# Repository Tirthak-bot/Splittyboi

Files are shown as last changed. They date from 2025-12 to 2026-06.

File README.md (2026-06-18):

# Splittyboi
A Split keyboard with low profile switches, Coded with KMK Firmware.

Split keeb Zine Page
Untitled design (1)

Making this because i want to try a split keeb :3

Using this is pretty straight forward obviously blehh, just connect it to the computer, flash the firmware once and it should just work like a regular keeb moving forward :)

# Schematic
This is the schematic for a single side, both sides are made identically.



# Layout
The layout was designed on https://www.keyboard-layout-editor.com/, The firmware hasn't yet been edited to match this layout and is currently sitting with placeholders.



# PCB
The PCB was designed in Kicad. The matrix wasn't properly aligned to make the look of the PCB More intresting, it will be coded in properly afterwards (Once I make it IRL).




# Case
The case was designed in Fusion. Both sides of the case are based on the same footprint but once it is extruded in the positive axis and once in negetive axis to get a identical case accommodating both right and left sides.

You just drop the pcb in place :) and for the both halfs of the case, they join using magnets!

The magnets are glue and drop, not press fit! So the thin walls around the magnet holes won't cause any problems!

Split_keeb_final_assembly_2026-Jun-13_07-47-10AM-000_CustomizedView16534653009

# Firmware
As mentioned above, the firmware is written in python using the KMK Libraries. It will be pushed to the microcontroller using circuit python.

# BOM
|SR.NO|ITEMS|QUANTITY|UNIT PRICE|TOTAL PRICE|URL|
|-----|-----|---|---|---|---|
|1|PCB (From JLCPCB)|5 (Minimun)|$10 (Including Shipping)|$50|In my Cart|
|2|Seeed XIAO nRF52840|2 (One for each side)|$12.50 (Including Shipping)|$25|https://robocraze.com/products/seeed-studio-xiao-nrf52840-development-board-supports-bluetooth-5-0|
|3|Gateron LP 2.0 Switches|70|$0.185 (Including Shipping)|$13|https://meckeys.com/shop/accessories/keyboard-accessories/key-switches/gateron-low-profile-2-0-mechanical-switch-3pin/|
|4|Blank DSA Keycaps 1U|70|$0.207 (Including Shipping)|$14.5|https://meckeys.com/shop/accessories/keyboard-accessories/keycaps/blank-dsa-keycaps-1u/|
|5|3.7V LiPo Batteries|2 (One for each side)|$1.615 (Including Shipping)|$3.23|https://quartzcomponents.com/products/3-7v-1000mah-li-po-rechargeable-battery|
|6|1N4148WS T4 Switching Diode|70|$0.025 (Including Shipping)|$1.78|https://quartzcomponents.com/collections/smd-diodes/products/1n4148ws-t4-switching-diode-sod-123-smd-package|
|7|3D Prints|4 Files|idk|idk|Self printed|
|8|Magnets|14|$0|$0|Self sourced|
|Total:|||-|$110||

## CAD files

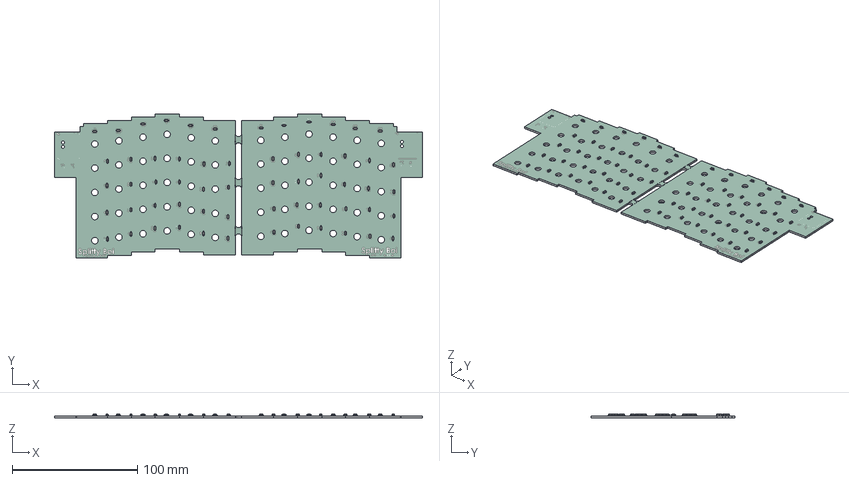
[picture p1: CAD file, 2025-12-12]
CAD/Extras/Split Keyboard PCB.step
294.2 x 115.0 x 2.90 mm
D_SOD-123 x 60
Split Keyboard_silkscreen
Split Keyboard_soldermask x 2
Split Keyboard_PCB

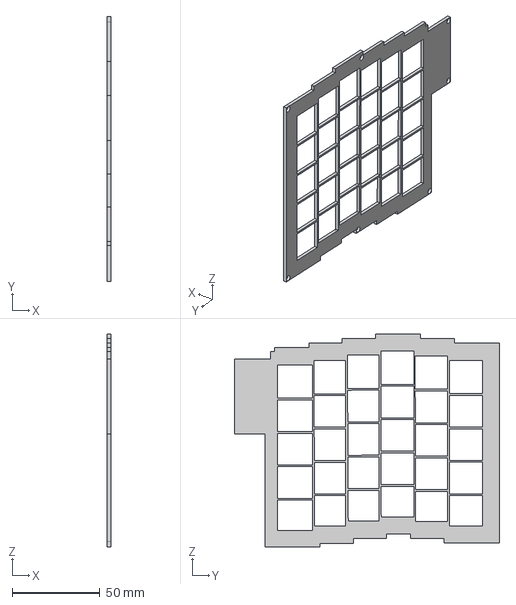
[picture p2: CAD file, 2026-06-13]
CAD/Right TOP.step
2.00 x 150.8 x 121.0 mm

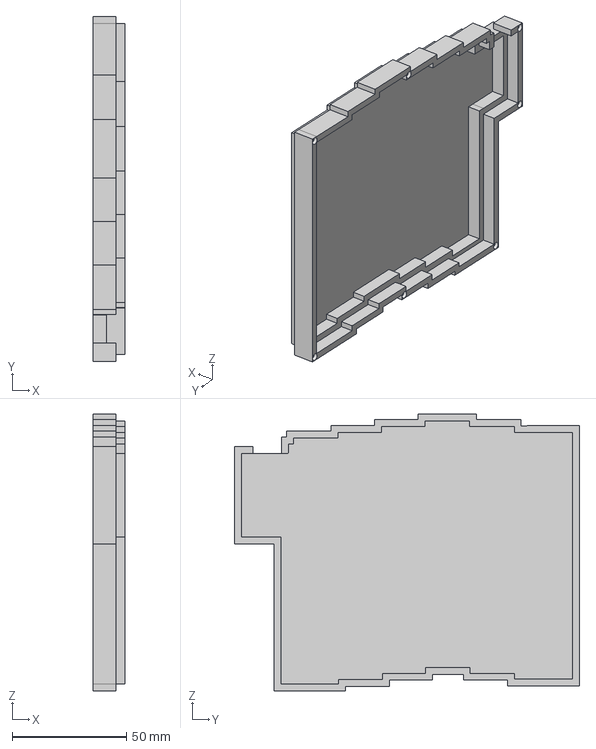
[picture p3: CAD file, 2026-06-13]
CAD/Left BOTTOM.step
14.0 x 150.8 x 121.0 mm

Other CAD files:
CAD/Left TOP.step
CAD/Right BOTTOM.step

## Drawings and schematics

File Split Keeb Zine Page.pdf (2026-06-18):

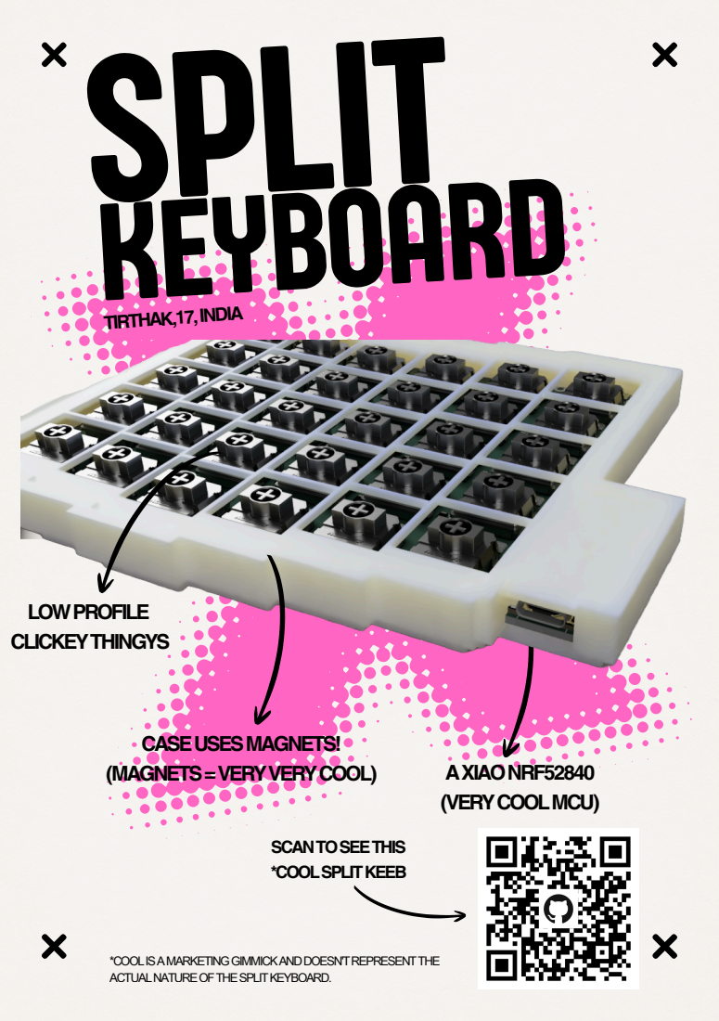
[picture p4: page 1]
LOWPROFILE CLICKEYTHINGYS; SPLIT KEYBOARD; AXIAONRF52840 (VERYCOOLMCU); CASEUSESMAGNETS! (MAGNETS=VERYVERYCOOL); *COOLISAMARKETINGGIMMICKANDDOESN'TREPRESENTTHE ACTUALNATUREOFTHESPLITKEYBOARD.; SCANTOSEETHIS *COOLSPLITKEEB; TIRTHAK,17,INDIA

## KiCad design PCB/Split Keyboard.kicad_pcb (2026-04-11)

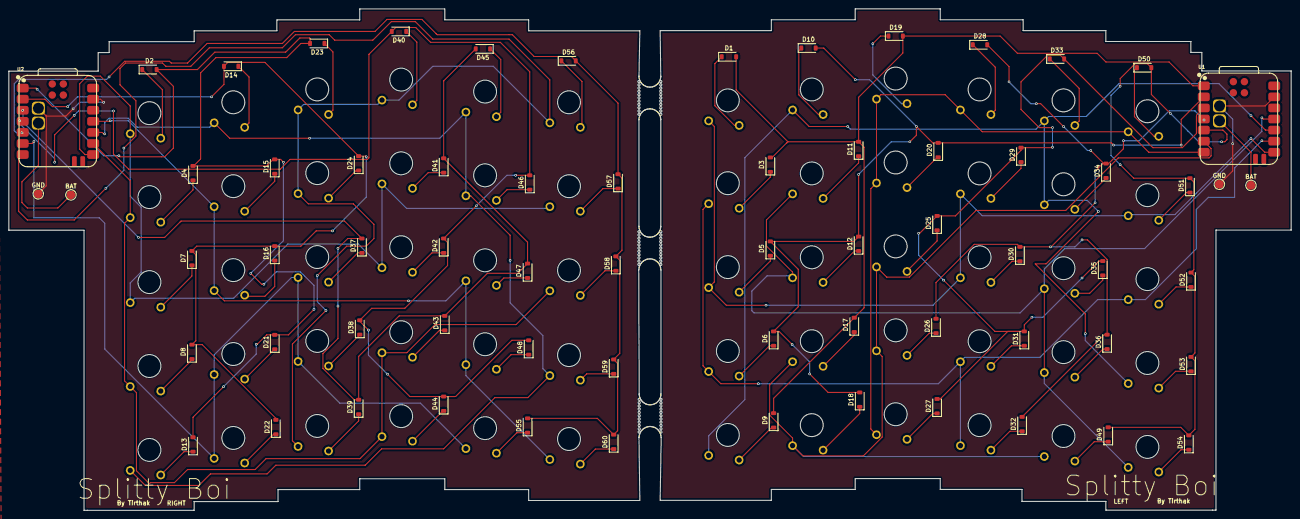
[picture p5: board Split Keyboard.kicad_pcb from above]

Board: 2 copper layers, 294.2 x 115.0 mm, 129 parts (0 on the bottom side), 74 nets.

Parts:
BAT: BAT; TestPoint_Pad_D2.0mm
BAT#2: BAT; TestPoint_Pad_D2.0mm
D1, D2, D3, D4, D5, D6, D7, D8, D9, D10, D11, D12, D13, D14, D15, D16, D17, D18, D19, D20, D21, D22, D23, D24, D25, D26, D27, D28, D29, D30, D31, D32, D33, D34, D35, D36, D37, D38, D39, D40, D41, D42, D43, D44, D45, D46, D47, D48, D49, D50, D51, D52, D53, D54, D55, D56, D57, D58, D59, D60: D; D_SOD-123
GND: GND; TestPoint_Pad_D2.0mm
GND#2: GND; TestPoint_Pad_D2.0mm
SW1, SW2, SW3, SW4, SW5, SW6, SW7, SW8, SW9, SW10, SW11, SW12, SW13, SW14, SW15, SW16, SW17, SW18, SW19, SW20, SW21, SW22, SW23, SW24, SW25, SW26, SW27, SW28, SW29, SW30, SW31, SW32, SW33, SW34, SW35, SW36, SW37, SW38, SW39, SW40, SW41, SW42, SW43, SW44, SW45, SW46, SW47, SW48, SW49, SW50, SW51, SW52, SW53, SW54, SW55, SW56, SW57, SW58, SW59, SW60: SW_Push; SW_KS33_1u
U1, U2: XIAO-nRF52840-SMD; modified-XIAO-nRF52840-SMD
mouse-bite-5mm-slot, mouse-bite-5mm-slot#2, mouse-bite-5mm-slot#3: VAL**; mouse-bite-5mm-slot

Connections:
COL0: D1.2 (A), D2.2 (A), D3.2 (A), D4.2 (A), D9.2 (A), D11.2 (A), D13.2 (A), D15.2 (A), D17.2 (A), D19.2 (A), D21.2 (A), D23.2 (A), U1.1 (P0.02_A0_D0), U2.1 (P0.02_A0_D0)
COL1: D5.2 (A), D6.2 (A), D7.2 (A), D8.2 (A), D10.2 (A), D12.2 (A), D14.2 (A), D16.2 (A), D18.2 (A), D20.2 (A), D22.2 (A), D24.2 (A), U1.2 (P0.03_A1_D1), U2.2 (P0.03_A1_D1)
COL2: D25.2 (A), D27.2 (A), D29.2 (A), D31.2 (A), D33.2 (A), D35.2 (A), D37.2 (A), D39.2 (A), D41.2 (A), D43.2 (A), D45.2 (A), D47.2 (A), U1.3 (P0.28_A2_D2), U2.3 (P0.28_A2_D2)
COL3: D26.2 (A), D28.2 (A), D30.2 (A), D32.2 (A), D34.2 (A), D36.2 (A), D38.2 (A), D40.2 (A), D42.2 (A), D44.2 (A), D46.2 (A), D48.2 (A), U1.4 (P0.29_A3_D3), U2.4 (P0.29_A3_D3)
COL4: D49.2 (A), D50.2 (A), D51.2 (A), D52.2 (A), D53.2 (A), D54.2 (A), D55.2 (A), D56.2 (A), D57.2 (A), D58.2 (A), D59.2 (A), D60.2 (A), U1.5 (P0.04_A4_D4_SDA), U2.5 (P0.04_A4_D4_SDA)
GND: GND.1, GND#2.1, U1.13 (GND), U1.16 (GND), U2.13 (GND), U2.16 (GND)
unnamed: D1.1 (K), SW1.2
unnamed: D2.1 (K), SW2.2
unnamed: D3.1 (K), SW3.2
unnamed: D4.1 (K), SW4.2
unnamed: D5.1 (K), SW5.2
unnamed: D6.1 (K), SW6.2
unnamed: D7.1 (K), SW7.2
unnamed: D8.1 (K), SW8.2
unnamed: D9.1 (K), SW9.2
unnamed: D10.1 (K), SW10.2
unnamed: D11.1 (K), SW11.2
unnamed: D12.1 (K), SW12.2
unnamed: D13.1 (K), SW13.2
unnamed: D14.1 (K), SW14.2
unnamed: D15.1 (K), SW15.2
unnamed: D16.1 (K), SW16.2
unnamed: D17.1 (K), SW17.2
unnamed: D18.1 (K), SW18.2
unnamed: D19.1 (K), SW19.2
unnamed: D20.1 (K), SW20.2
unnamed: D21.1 (K), SW21.2
unnamed: D22.1 (K), SW22.2
unnamed: D23.1 (K), SW23.2
unnamed: D24.1 (K), SW24.2
unnamed: D25.1 (K), SW25.2
unnamed: D26.1 (K), SW26.2
unnamed: D27.1 (K), SW27.2
unnamed: D28.1 (K), SW28.2
unnamed: D29.1 (K), SW29.2
unnamed: D30.1 (K), SW30.2
unnamed: D31.1 (K), SW31.2
unnamed: D32.1 (K), SW32.2
unnamed: D33.1 (K), SW33.2
unnamed: D34.1 (K), SW34.2
unnamed: D35.1 (K), SW35.2
unnamed: D36.1 (K), SW36.2
unnamed: D37.1 (K), SW37.2
unnamed: D38.1 (K), SW38.2
unnamed: D39.1 (K), SW39.2
unnamed: D40.1 (K), SW40.2
unnamed: D41.1 (K), SW41.2
unnamed: D42.1 (K), SW42.2
unnamed: D43.1 (K), SW43.2
unnamed: D44.1 (K), SW44.2
unnamed: D45.1 (K), SW45.2
unnamed: D46.1 (K), SW46.2
unnamed: D47.1 (K), SW47.2
unnamed: D48.1 (K), SW48.2
unnamed: D49.1 (K), SW49.2
unnamed: D50.1 (K), SW50.2
unnamed: D51.1 (K), SW51.2
unnamed: D52.1 (K), SW52.2
unnamed: D53.1 (K), SW53.2
unnamed: D54.1 (K), SW54.2
unnamed: D55.1 (K), SW55.2
unnamed: D56.1 (K), SW56.2
unnamed: D57.1 (K), SW57.2
unnamed: D58.1 (K), SW58.2
unnamed: D59.1 (K), SW59.2
unnamed: D60.1 (K), SW60.2
unnamed: BAT.1, U1.15 (BAT)
unnamed: BAT#2.1, U2.15 (BAT)
ROW0: SW17.1, SW18.1, SW21.1, SW22.1, SW25.1, SW26.1, SW37.1, SW38.1, SW49.1, SW55.1, U1.6 (P0.05_A5_D5_SCL), U2.6 (P0.05_A5_D5_SCL)
ROW1: SW19.1, SW20.1, SW23.1, SW24.1, SW27.1, SW28.1, SW39.1, SW40.1, SW50.1, SW56.1, U1.7 (P1.11_D6_TX), U2.7 (P1.11_D6_TX)
ROW2: SW1.1, SW2.1, SW5.1, SW7.1, SW29.1, SW30.1, SW41.1, SW42.1, SW51.1, SW57.1, U1.8 (P1.12_D7_RX), U2.8 (P1.12_D7_RX)
ROW3: SW3.1, SW4.1, SW6.1, SW8.1, SW31.1, SW32.1, SW43.1, SW44.1, SW52.1, SW58.1, U1.9 (P1.13_D8_SCK), U2.9 (P1.13_D8_SCK)
ROW4: SW9.1, SW10.1, SW13.1, SW14.1, SW33.1, SW34.1, SW45.1, SW46.1, SW53.1, SW59.1, U1.10 (P1.14_D9_MISO), U2.10 (P1.14_D9_MISO)
ROW5: SW11.1, SW12.1, SW15.1, SW16.1, SW35.1, SW36.1, SW47.1, SW48.1, SW54.1, SW60.1, U1.11 (P1.15_D10_MOSI), U2.11 (P1.15_D10_MOSI)

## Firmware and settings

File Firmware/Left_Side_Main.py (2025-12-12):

import board
import time

from kmk.kmk_keyboard import KMKKeyboard
from kmk.scanners import DiodeOrientation
from kmk.keys import KC, Key
from kmk.modules.split import Split, SplitType, SplitSide

# Pretty sure that left side is the master side.
# Need to add more libreries for adding diffrent functions and also obviously remap the keys.
# Note:  Matrix in my keyboard isn't perfectly alligned so some keys may not work as expected and the key mapping may need to be adjusted accordingly.

keyboard = KMKKeyboard()

keyboard.col_pins = (board.D0, board.D1, board.D2, board.D3, board.D4)
keyboard.row_pins = (board.D5, board.D6, board.D7, board.D8, board.D9, board.D10)


keyboard.diode_orientation = DiodeOrientation.COL2ROW

split = Split(
    split_type=SplitType.BLE,
    split_side=SplitSide.LEFT
)
keyboard.modules.append(split)

keyboard.keymap = [ KC.N1, KC.N2, KC.N3, KC.N4, KC.N5,KC.N6,
                    KC.N7, KC.N8, KC.N9, KC.A, KC.B, KC.C,
                    KC.D, KC.E, KC.F, KC.G, KC.H, KC.I,
                    KC.J, KC.K, KC.L, KC.M, KC.N, KC.O,
                    KC.P, KC.Q, KC.R, KC.S, KC.T, KC.U,
]

if __name__ == '__main__':
    keyboard.go()
